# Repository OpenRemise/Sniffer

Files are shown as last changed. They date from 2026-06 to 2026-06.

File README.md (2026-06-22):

# Sniffer



<a href="https://openremise.at">
<picture>
  <source media="(prefers-color-scheme: dark)" srcset="https://github.com/OpenRemise/.github/raw/master/data/icons/icon_dark.svg">
  
</picture>
</a>

The Sniffer is a small add-on board that turns a [Raspberry Pi Pico](https://www.raspberrypi.com/products/raspberry-pi-pico) into a [DCC](https://en.wikipedia.org/wiki/Digital_Command_Control) (and BiDi) logic analyzer.

### Features
- **Requires** [Raspberry Pi Pico](https://www.raspberrypi.com/products/raspberry-pi-pico) (or [Pico 2](https://www.raspberrypi.com/products/raspberry-pi-pico-2))
- No external supply
- ≥12V track voltage
- 3.3V logic level outputs for
  - P track
  - N track
  - BiDi
  - BiDi polarity
- Opto-isolation
- Supported software
  - [PulseView](https://github.com/sigrokproject/pulseview)
  - [LogicAnalyzer](https://github.com/gusmanb/logicanalyzer)

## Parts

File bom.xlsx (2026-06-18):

 |  |  | S3Main PCS BOM
Item # | *Designator | *Qty | Manufacturer | *Mfg Part # | Description / Value | *Package/Footprint | Type | Your Instructions / Notes
1 | A1 | 1 | Raspberry Pi | SC1631 | RASPBERRY PI PICO 2 RP2350 |  | SMD
2 | C1,C2,C4,C5 | 4 | Samsung Electro-Mechanics | CL31B225KBHNNNE | CAP CER 2.2UF 50V X7R 1206 | 1206 | SMD
3 | C3,C6,C7 | 3 | Samsung Electro-Mechanics | CL21B104KBCNNNC | CAP CER 0.1UF 50V X7R 0805 | 0805 | SMD
4 | D1,D2 | 2 | Diodes Incorporated | SBRT5A50SA-13 | DIODE SBR 50V 5A SMA | SMA | SMD
5 | D3,D4 | 2 | Diodes Incorporated | 1N4148WS-7-F | DIODE STANDARD 75V 150MA SOD323 | SOD-323 | SMD
6 | J1,J2 | 2 | Phoenix Contact | 1844210 | TERM BLOCK HDR 2POS 90DEG 3.5MM |  | THT
7 | Q1,Q2,Q3,Q4 | 4 | Taiwan Semiconductor Corporation | BC857A RFG | TRANS PNP 45V 0.1A SOT-23 | SOT-23-3 | SMD
8 | R1,R3,R10,R11,R12,R13,R16 | 7 | YAGEO | RC0805FR-0710KL | RES 10K OHM 1% 1/8W 0805 | 0805 | SMD
9 | R2 | 1 | Vishay Dale | RCS08053R30FKEA | RES 3.3 OHM 1% 3/4W 0805 | 0805 | SMD
10 | R4,R7,R8 | 3 | YAGEO | RC0805FR-07100RL | RES 100 OHM 1% 1/8W 0805 | 0805 | SMD
11 | R5 | 1 | YAGEO | RC0805FR-07220RL | RES 220 OHM 1% 1/8W 0805 | 0805 | SMD
12 | R6,R14,R15,R17,R18,R19,R20,R21 | 8 | YAGEO | RC0805FR-072K2L | RES 2.2K OHM 1% 1/8W 0805 | 0805 | SMD
13 | R9 | 1 | YAGEO | RC0805FR-074K7L | RES 4.7K OHM 1% 1/8W 0805 | 0805 | SMD
14 | U1 | 1 | onsemi | LM393DR2G | IC COMPARATOR 2 GEN PUR 8SOIC | SOIC-8 | SMD
15 | U2 | 1 | EVVO | TL431A | V-REF ADJUSTABLE 2.5V TO 36V 100 | SOT-23-3 | SMD
16 | U3 | 1 | Shenzhen Slkormicro Semicon Co., Ltd. | SLHT50H | 250MA FIXED 5V POSITIVE 50V SOT- | SOT-23-3 | SMD | Alternatively AP7375-50SR-7
17 | U4,U5 | 2 | onsemi | HCPL2630SDM | OPTOISO 5KV 2CH OPEN COLL 8-SMD | SMD-8 | SMD

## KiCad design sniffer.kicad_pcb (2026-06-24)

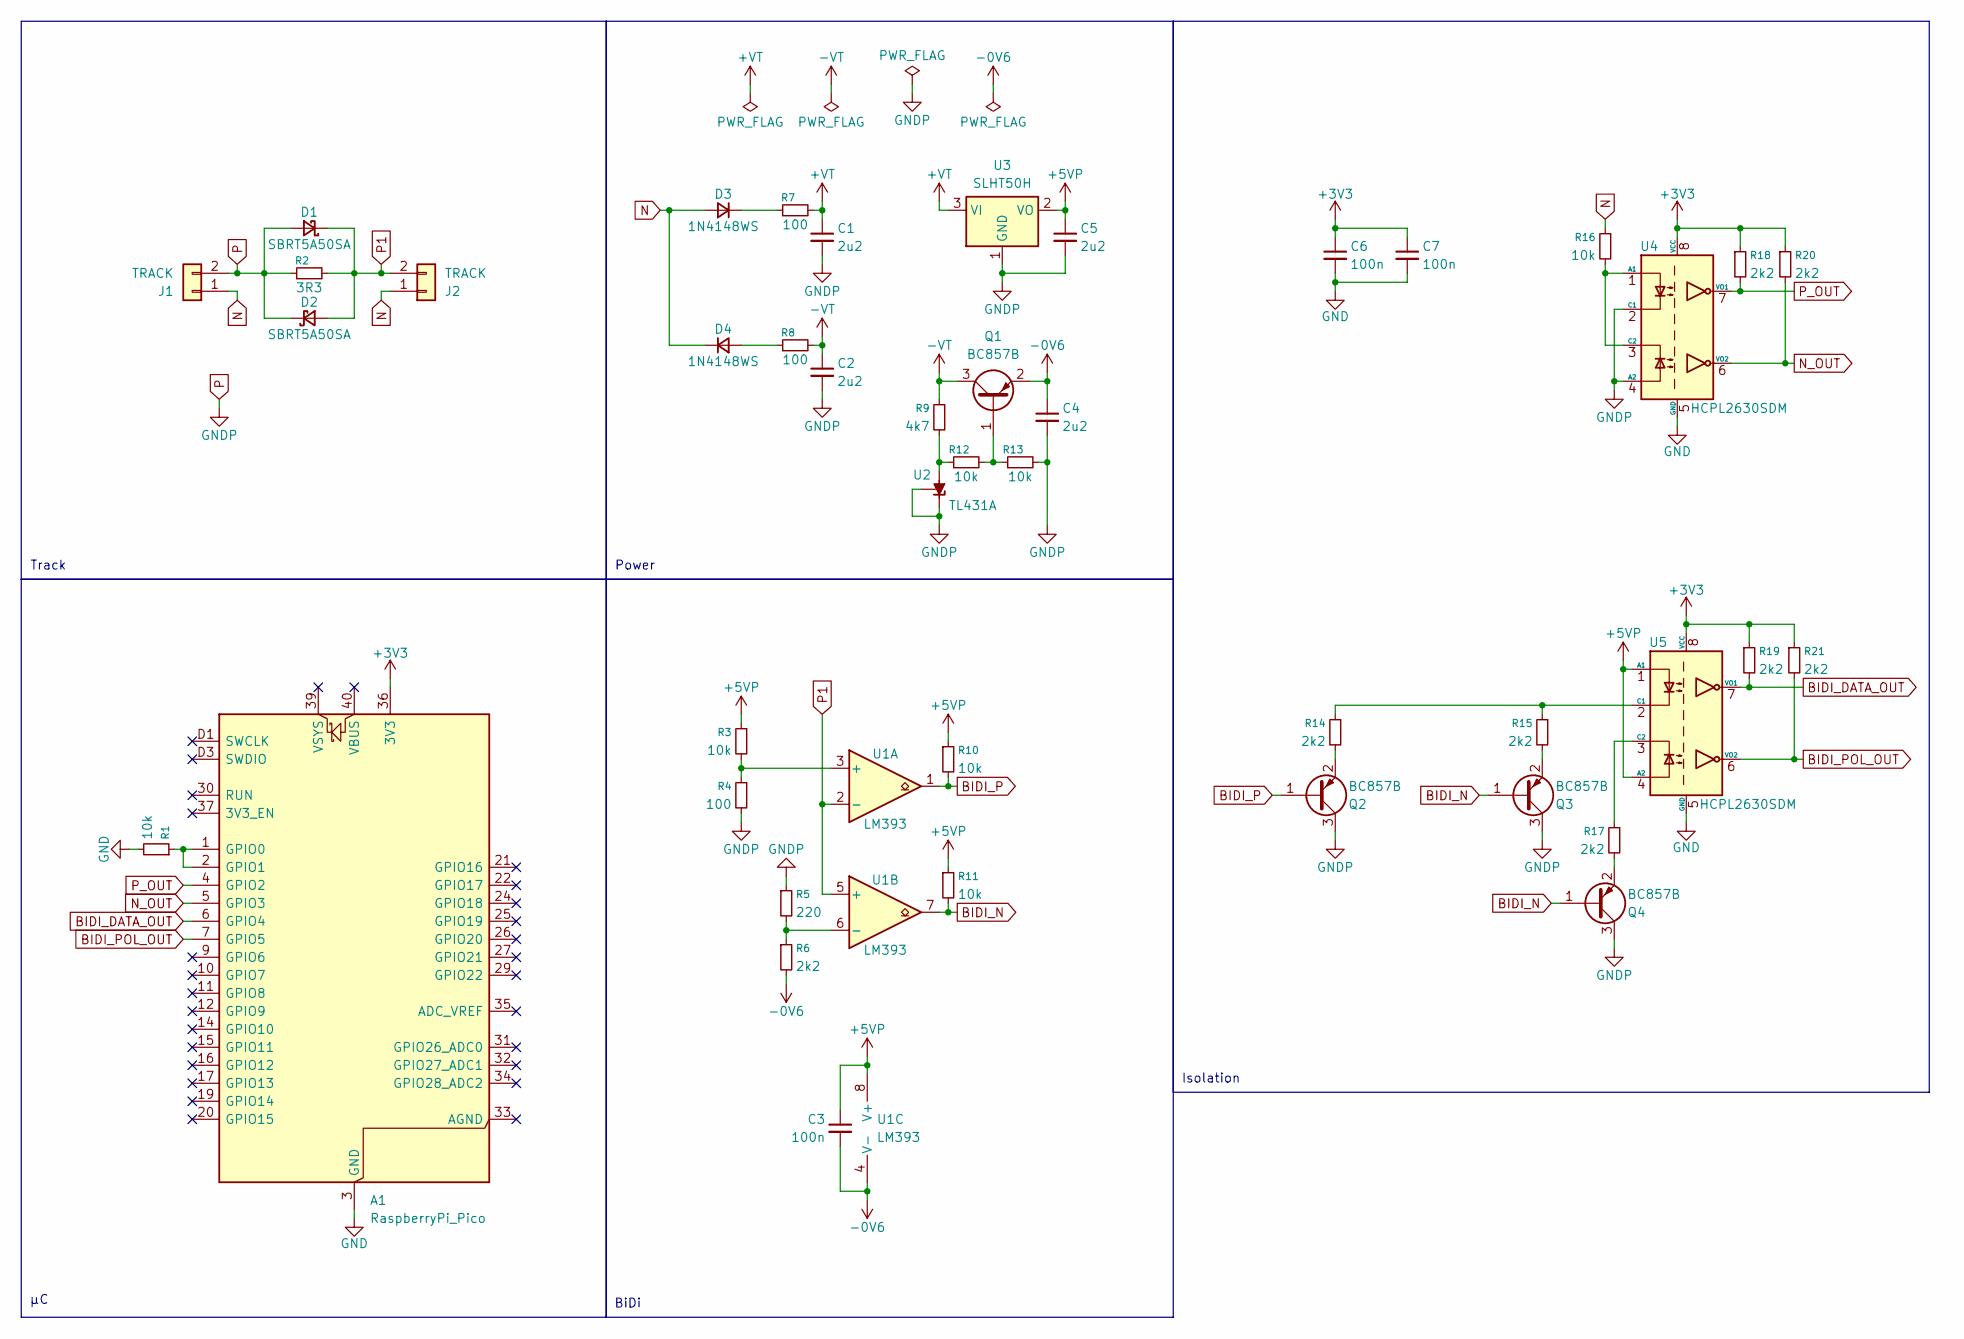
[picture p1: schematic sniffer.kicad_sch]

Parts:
A1: RaspberryPi_Pico; RaspberryPi_Pico_SMD_HandSolder
C1, C2, C4, C5: 2u2; C_1206_3216Metric_Pad1.33x1.80mm_HandSolder
C3, C6, C7: 100n; C_0805_2012Metric_Pad1.18x1.45mm_HandSolder
D1, D2: SBRT5A50SA; D_SMA_Handsoldering
D3, D4: 1N4148WS; D_SOD-323_HandSoldering
J1, J2: TRACK; PhoenixContact_MC_1,5_2-G-3.5_1x02_P3.50mm_Horizontal
Q1, Q2, Q3, Q4: BC857B; SOT-23_Handsoldering
R1, R3, R10, R11, R12, R13, R16: 10k; R_0805_2012Metric_Pad1.20x1.40mm_HandSolder
R2: 3R3; R_0805_2012Metric_Pad1.20x1.40mm_HandSolder
R4, R7, R8: 100; R_0805_2012Metric_Pad1.20x1.40mm_HandSolder
R5: 220; R_0805_2012Metric_Pad1.20x1.40mm_HandSolder
R6, R14, R15, R17, R18, R19, R20, R21: 2k2; R_0805_2012Metric_Pad1.20x1.40mm_HandSolder
R9: 4k7; R_0805_2012Metric_Pad1.20x1.40mm_HandSolder
U1: LM393; SOIC-8_3.9x4.9mm_P1.27mm
U2: TL431A; SOT-23_Handsoldering
U3: SLHT50H; SOT-23_Handsoldering
U4, U5: HCPL2630SDM; SMDIP-8_W9.53mm

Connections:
+3V3: A1.36 (3V3), C6.1, C7.1, R18.1, R19.1, R20.1, R21.1, U4.8 (VCC), U5.8 (VCC)
+5VP: C3.1, C5.1, R3.1, R10.1, R11.1, U1.8 (V+), U3.2 (VO), U5.1 (A1), U5.4 (A2)
+VT: C1.1, R7.2, U3.3 (VI)
-0V6: C3.2, C4.1, Q1.2 (E), R6.2, U1.4 (V-)
-VT: C2.1, Q1.3 (C), R8.2, R9.1
BIDI_DATA_OUT: A1.6 (GPIO4), R19.2, U5.7 (VO1)
BIDI_N: Q3.1 (B), Q4.1 (B), R11.2, U1.7
BIDI_P: Q2.1 (B), R10.2, U1.1
BIDI_POL_OUT: A1.7 (GPIO5), R21.2, U5.6 (VO2)
GND: A1.3 (GND), A1.8 (GND), A1.13 (GND), A1.18 (GND), A1.23 (GND), A1.28 (GND), A1.38 (GND), A1.D2 (GND), C6.2, C7.2, R1.2, U4.5 (GND), U5.5 (GND)
N: D3.2 (A), D4.1 (K), J1.1, J2.1, R16.1
N_OUT: A1.5 (GPIO3), R20.2, U4.6 (VO2)
unnamed: A1.1 (GPIO0), A1.2 (GPIO1), R1.1
unnamed: D3.1 (K), R7.1
unnamed: D4.2 (A), R8.1
unnamed: Q1.1 (B), R12.2, R13.1
unnamed: Q2.2 (E), R14.2
unnamed: Q3.2 (E), R15.2
unnamed: Q4.2 (E), R17.2
unnamed: R3.2, R4.1, U1.3 (+)
unnamed: R5.2, R6.1, U1.6 (-)
unnamed: R9.2, R12.1, U2.3 (A)
unnamed: R16.2, U4.1 (A1), U4.3 (C2)
unnamed: R14.1, R15.1, U5.2 (C1)
unnamed: R17.1, U5.3 (C2)
P: C1.2, C2.2, C4.2, C5.2, D1.2 (A), D2.1 (K), J1.2, Q2.3 (C), Q3.3 (C), Q4.3 (C), R2.1, R4.2, R5.1, R13.2, U2.1 (K), U2.2 (REF), U3.1 (GND), U4.2 (C1), U4.4 (A2)
P1: D1.1 (K), D2.2 (A), J2.2, R2.2, U1.2 (-), U1.5 (+)
P_OUT: A1.4 (GPIO2), R18.2, U4.7 (VO1)

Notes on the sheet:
BiDi
Isolation
Track
Power

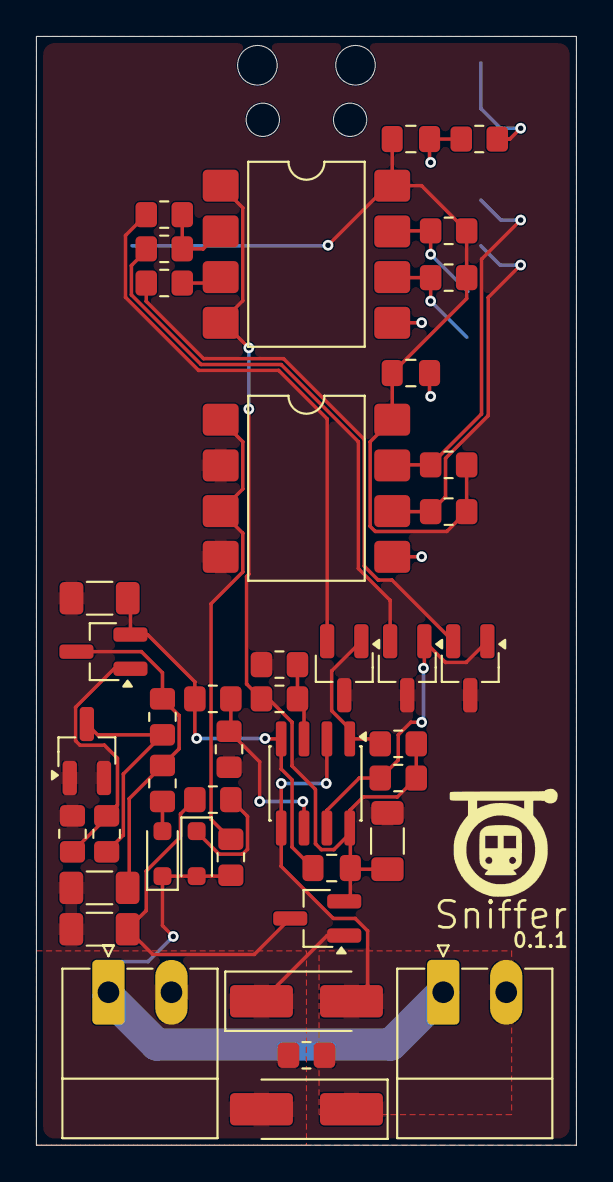
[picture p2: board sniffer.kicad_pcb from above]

Board: 2 copper layers, 30.0 x 61.6 mm, 44 parts (1 on the bottom side), 28 nets.

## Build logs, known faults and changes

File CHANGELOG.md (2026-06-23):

# Changelog

## 0.1.1
- U3 regulator pins flipped ([#1](https://github.com/OpenRemise/Sniffer/issues/1))

## 0.1.0
- Initial version

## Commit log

2026-06-18 feat: revision 0.1.0
    [bom.xlsx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]
2026-06-23 fix: U3 regulator pins flipped (#1)
    [sniffer.kicad_pcb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]
2026-06-24 chore: suitable names for `BIDI_DATA` and `BIDI_POL`
    [sniffer.kicad_pcb, sniffer.kicad_sch]
